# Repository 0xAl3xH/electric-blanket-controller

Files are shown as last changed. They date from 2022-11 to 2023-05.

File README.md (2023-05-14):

# Electric Blanket Controller 

## About The Project

An excellent way to stay warm while camping/overlanding on a tight electrical energy budget is with a 12V electric blanket. With a blanket such as [this one](https://www.amazon.com/gp/product/B01N21MI0Z) under a sleeping bag, you can stay fairly warm. However, these blankets don't typically come with temperature control and you can easily overheat a couple hours after power on. In addition to it being uncomfortable, there's power being wasted here to achieve a comfortable temperature. The electric blanket controller uses a MOSFET as a switch to apply a duty cycle to the power coming into the blanket, giving users a choice between different levels of heat. 

## Goals

- [ ] Efficient - as most users are using 12V electric blankets off grid, it's important that the controller doesn't dissipate much power
- [ ] Easy to use - no modifications to the blankets or car power port, plug and play
- [ ] Replicable - so more overlanders can stop overheating with these blankets and save energy

## Milestones

- [ x ] Find appropriate hardware for controller
- [ x ] Test hardware and find duty cycle
- [ x ] Create PCB 
- [ x ] Write firmware
- [ x ] Test firmware
- [ x ] Build controller on real PCB with v1.0.0 firmware
- [ x ] Design a 3D printed case

## Getting Started

Flash the `.ino` file using your favorite ATTiny programmer. I didn't have one handy so ended up using an [Arduino Uno](https://www.instructables.com/How-to-Program-an-Attiny85-From-an-Arduino-Uno) to flash the ATTiny. The ATTiny needs to run at 1 MHz clock for this project, which should be the default from factory. The `hardware` directory contains the circuit board schematic and board files in `pcb` as well as a 3D printed case with tight and loose tolerances to account for the variablility in 3D printers. 

## License

Distributed under the MIT License. See LICENSE.txt for more information.

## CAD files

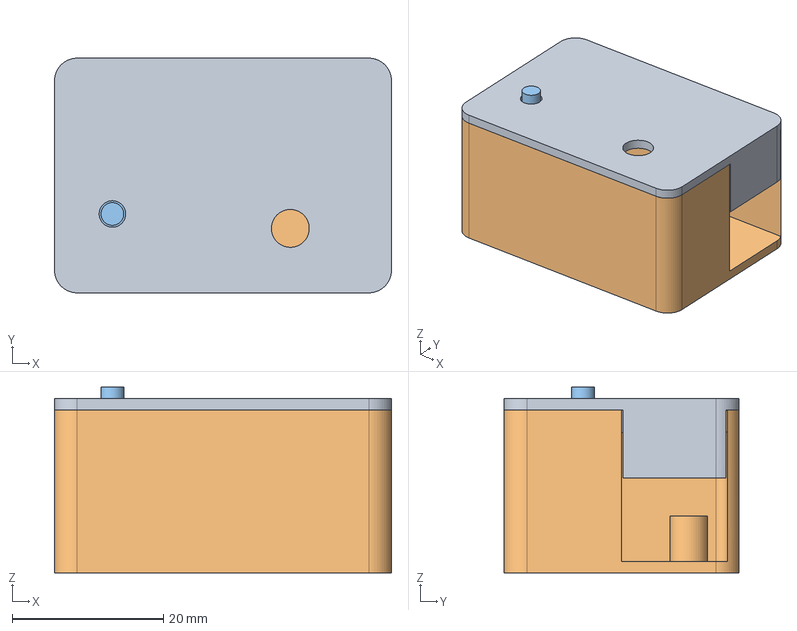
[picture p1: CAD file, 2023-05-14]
hardware/case/loose_tolerance/Case loose tolerance.step
44.5 x 31.0 x 24.5 mm
Cover
Case_1
Button Stalk

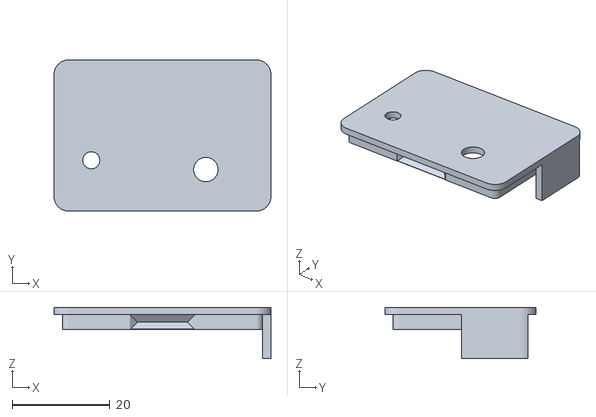
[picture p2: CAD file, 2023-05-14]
hardware/case/loose_tolerance/Cover loose tolerance.stl
44.5 x 31.0 x 10.5

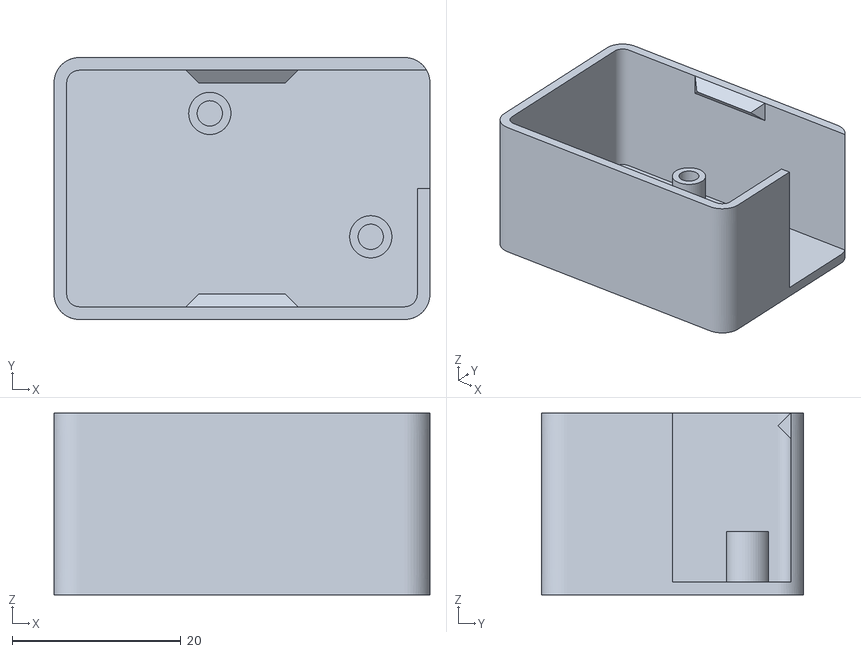
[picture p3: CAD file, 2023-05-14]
hardware/case/tight_tolerance/Bottom tight tolerance.stl
44.5 x 31.0 x 21.5

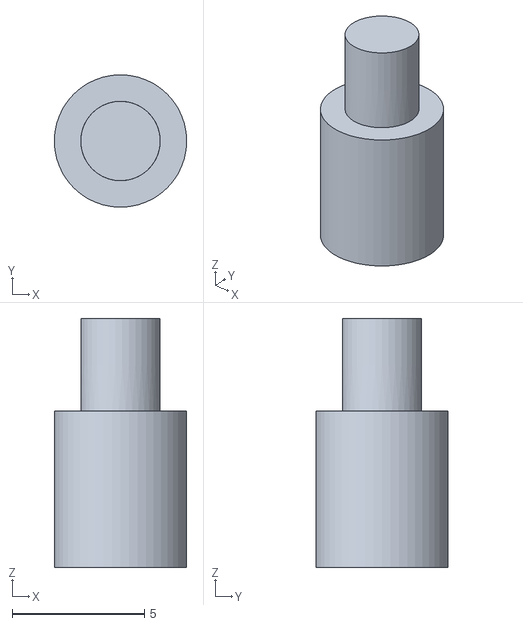
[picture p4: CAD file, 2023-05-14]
hardware/case/loose_tolerance/Button stalk loose tolerance.stl
5.00 x 5.00 x 9.40

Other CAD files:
hardware/case/tight_tolerance/Case tight tolerance.step
hardware/case/tight_tolerance/Cover tight tolerance.stl

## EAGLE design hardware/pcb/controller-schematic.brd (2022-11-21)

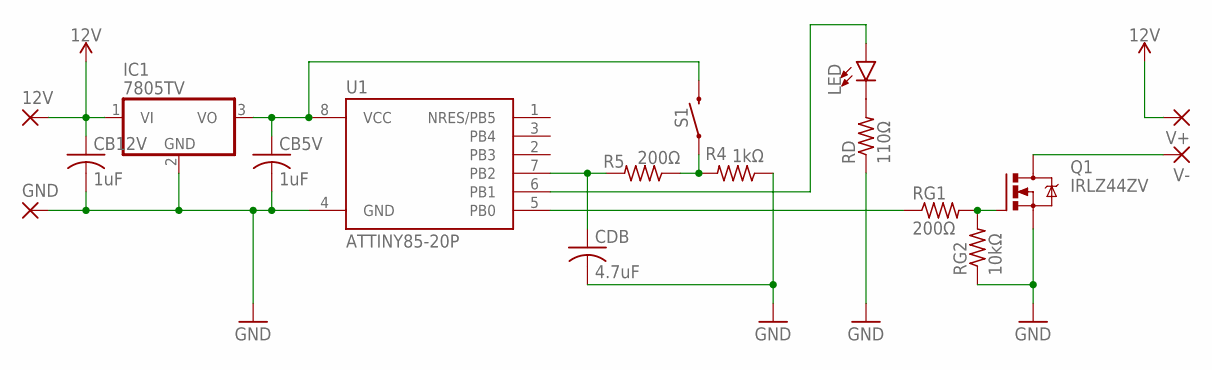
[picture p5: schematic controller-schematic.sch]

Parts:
12V: SMD5; SMD2,54-5,08
CB5V, CB12V: 1uF; C050-030X075
CDB: 4.7uF; C050-030X075
GND: SMD5; SMD2,54-5,08
IC1: 7805TV; TO220V
LED: LED3MM; LED_3MM
Q1: IRLZ44ZV; TO220BV
R4: 1kΩ; 0207/7
R5: 200Ω; 0207/7
RD: 110Ω; 0207/7
RG1: 200Ω; 0207/7
RG2: 10kΩ; 0207/7
S1: MOMENTARY-SWITCH-SPST-PTH-6.0MM; TACTILE_SWITCH_PTH_6.0MM
U1: ATTINY85-20P; PDIP08_300MIL
V+: SMD5; SMD2,54-5,08
V-: SMD5; SMD2,54-5,08

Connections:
5V: CB5V.1, IC1.3 (VO), S1.3 (2), U1.8 (VCC)
12V: 12V.1, CB12V.1, IC1.1 (VI), V+.1
GND: CB5V.2, CB12V.2, CDB.2, GND.1, IC1.2 (GND), Q1.S, R4.1, RD.1, RG2.1, U1.4 (GND)
unnamed: RG1.1, U1.5 (PB0)
unnamed: Q1.G, RG1.2, RG2.2
unnamed: Q1.D, V-.1
unnamed: LED.K (C), RD.2
unnamed: LED.A, U1.6 (PB1)
unnamed: R4.2, R5.1, S1.1
unnamed: CDB.1, R5.2, U1.7 (PB2)

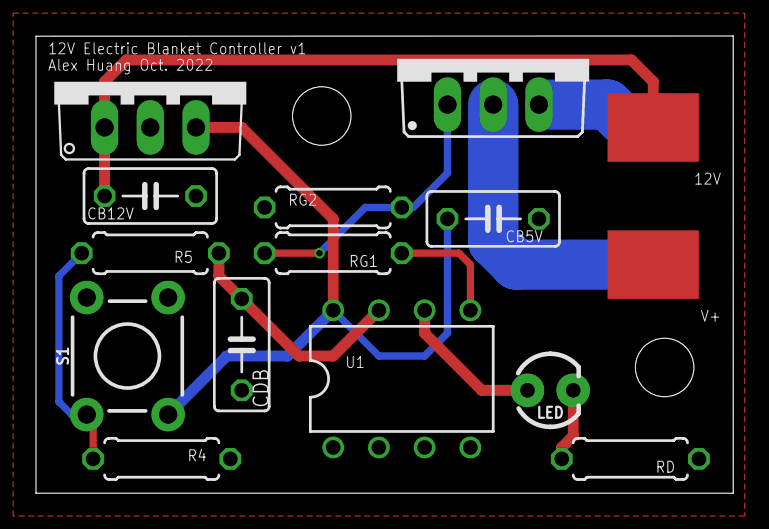
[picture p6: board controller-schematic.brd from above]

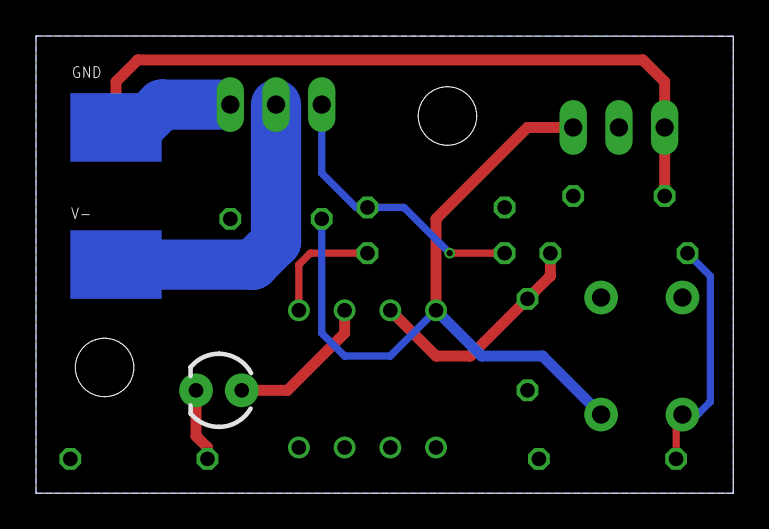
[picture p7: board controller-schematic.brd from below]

Board: 2 copper layers, 38.7 x 25.4 mm, 17 parts (2 on the bottom side), 10 nets.

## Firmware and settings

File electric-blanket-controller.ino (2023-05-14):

/*
 * The following firmware runs on an ATTiny85 at 1 MHz
 */

volatile uint8_t level = 1; // start with the blanket on 50% duty cycle
volatile unsigned long last_debounce_time = millis();
volatile unsigned long last_level_flash_time = millis();

/*
 * This timer interrupt handles switching the electric blanket off or on
 *
 * Assuming a 1 MHz clock and 1024 prescaler
 * 0.26 or roughly 0.25 seconds pass every time the
 * interrupt is triggered, so our duty cycle count should be
 * 8 total interrupt events
 */
volatile int interrupt_count = 0;
#define TOTAL_CYCLES 8
ISR(TIMER1_OVF_vect)
{
  if (interrupt_count < 2 * (level + 1))
  {
    PORTB |= _BV(PB0); // MOSFET on
  }
  else
  {
    PORTB &= ~_BV(PB0); // MOSFET off
  }
  interrupt_count = (interrupt_count + 1) % TOTAL_CYCLES;
}

/*
 * This external interrupt handles debouncing button input and
 * cycling through different power levels
 */
volatile unsigned long now;
volatile uint8_t state = 1;
volatile uint8_t reading = 0, last_button_state = 0, last_valid_reading = 0;
#define DEBOUNCE_DELAY 25 // ms
ISR(INT0_vect)
{
  now = millis();
  reading = bit_is_set(PINB, PB2);
  switch (state)
  {
  case 1: // wait for the rising edge / button press in this state
    if (reading)
    {
      last_debounce_time = now;
      state = 2;
    }
    break;
  case 2: // wait for the falling edge / button release in this state
    if (reading)
    { // invalid, go back to state 1
      state = 1;
    }
    else
    {
      // button press is valid if time between rising/falling edge exceeds
      // debounce delay
      bool valid = now - last_debounce_time > DEBOUNCE_DELAY;
      level = valid ? (level + 1) % 4 : level;
      last_level_flash_time = valid ? 0 : last_level_flash_time;
      state = 1;
    }
    break;
  default:
    state = 1;
  }
}

/*
 * Takes a positive integer as argument for how many times to flash LED
 */
#define PULSE_DURATION 250 // microseconds
#define FLASH_DURATION 300 // milliseconds
void flash_led(uint8_t num)
{
  while (num)
  {
    // pulse light
    PORTB |= _BV(PB1);
    delayMicroseconds(PULSE_DURATION);
    PORTB &= ~_BV(PB1);
    delay(FLASH_DURATION);
    num--;
  }
}

void setup()
{
  // setup pins
  DDRB |= _BV(PB0) | _BV(PB1); // pin 1 and pin 0 are outputs
  DDRB &= ~_BV(PB2);           // pin 2 is input

  // Timer 1
  TCCR1 = 0x00;
  TCCR1 |= (1 << CS13) | (1 << CS11) | (1 << CS10); // prescale timer by 1024
  TCNT1 = 0;
  TIMSK |= (1 << TOIE1); // enable TIMER0 interrupt

  // External interreupt INT0
  MCUCR |= _BV(ISC00); // trigger on any edge
  GIMSK |= _BV(INT0);  // enable INT0

  sei();
}

#define LEVEL_UPDATE_INTERVAL 1000 // ms
void loop()
{
  // periodically pulse LED to show current level
  if (millis() - last_level_flash_time >= LEVEL_UPDATE_INTERVAL)
  {
    flash_led(level + 1);
    last_level_flash_time = millis();
  }
}

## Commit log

2022-11-01 Design controller schematic and complete PCB layout
    [controller-schematic.brd, controller-schematic.sch]
2022-11-01 Fix LED not turning off in flash function
    [electric-blanket-controller.ino]
2022-11-21 Adjust LED flash timing for better UX
2022-11-21 Finish v1.0 firmware
    TODO: figure out why debounce doesn't work very well next time have
    access to oscilloscope
    [electric-blanket-controller.ino]
2022-11-21 Add passives values to schematic and board
    [controller-schematic.brd, controller-schematic.sch]
2022-11-21 Fix level being inverted bug and formatting
    [electric-blanket-controller.ino]
2023-05-14 Use state machine for button debouncing logic
2023-05-14 Make / move files to PCB directory
    [controller-schematic.brd, controller-schematic.sch]
2023-05-14 Add 3D printed case files
    [Bottom tight tolerance.stl, Button stalk loose tolerance.stl, Button stalk tight tolerance.stl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]

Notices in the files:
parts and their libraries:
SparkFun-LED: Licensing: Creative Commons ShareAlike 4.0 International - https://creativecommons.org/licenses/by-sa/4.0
